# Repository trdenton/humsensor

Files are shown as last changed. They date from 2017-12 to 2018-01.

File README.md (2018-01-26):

# Humidity Sensor Solution

A basic wireless humidity sensor solution.  A work in progress.  Get your PCBs at https://www.pcbway.com/project/shareproject/W04152ASD12_humxmit_v2.html

Check out the writeup here:
https://skullspace.ca/2017/12/23/wireless-humidity-sensor-part-1-hardware-design/

## Hardware

Check out the KiCAD design files for the transmitter/sensor in 'tx\_pcb'

## Software

### Receiver

The receiver is based on an arduino mega (due to what I had laying around) and an nRF24L01+ module.  The sketch can be fond in 'hum\_sw/humrx'

### Transmitter

The transmitter is based on an attiny87, si7006, and nrf24L01+.  You can find it's source code in 'hum\_sw/humtx'.  It requires avrlibc and GNU make.  the 'prog' subdirectory contains a scrip that will flash the transmitter PCB via avrdude.  The included copy of avrdude is for my convenience, it is compiled for linux amd64

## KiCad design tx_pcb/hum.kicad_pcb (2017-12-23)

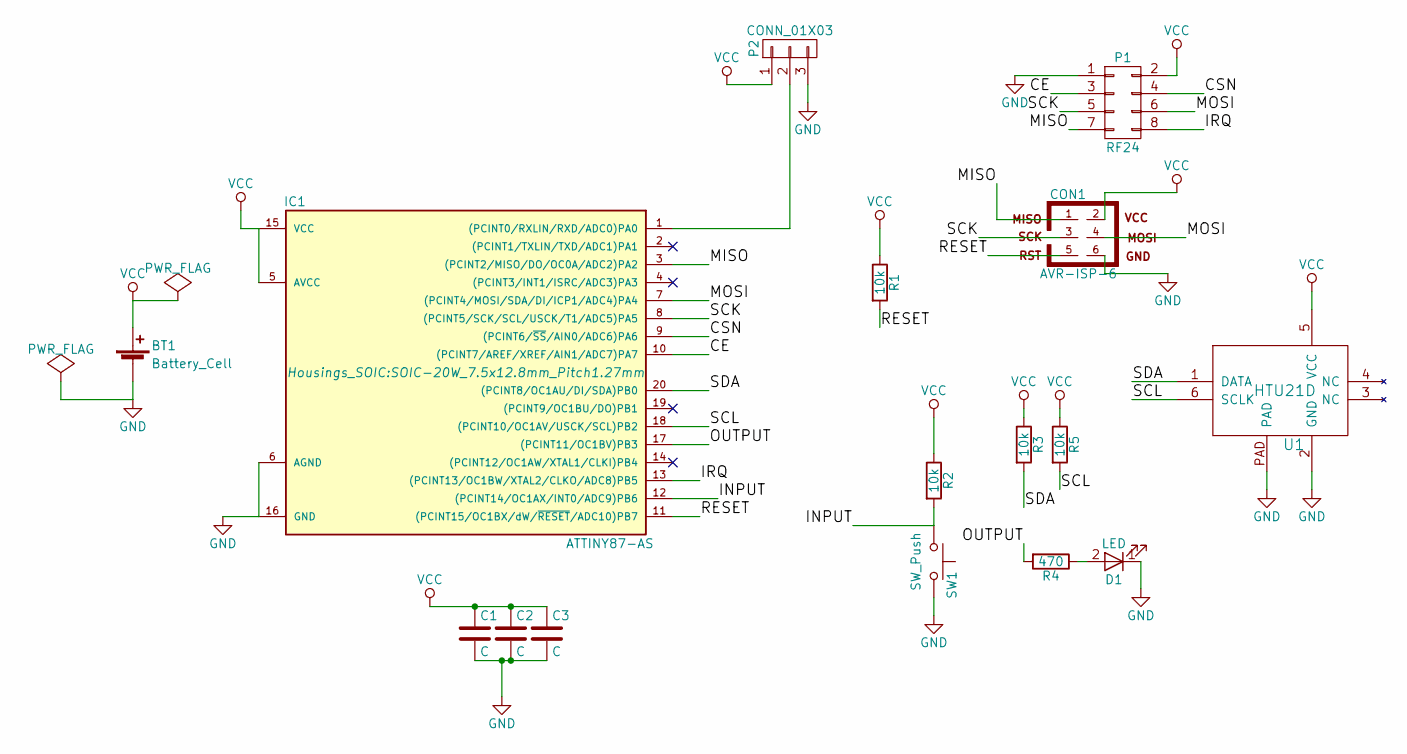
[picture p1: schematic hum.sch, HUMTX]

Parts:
BT1: Battery_Cell; battery
C1, C2, C3: C; C_0402
CON1: AVR-ISP-6; Pin_Header_Straight_2x03
D1: LED; LED_1206
IC1: ATTINY87-AS; SOIC-20W_7.5x12.8mm_Pitch1.27mm
P1: RF24; Socket_Strip_Straight_2x04
P2: CONN_01X03; Socket_Strip_Straight_1x03
R1, R2, R3, R5: 10k; R_0402
R4: 470; R_0402
SW1: SW_Push; switch
U1: HTU21D

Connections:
/CE: IC1.10 ((PCINT7/AREF/XREF/AIN1/ADC7)PA7), P1.3
/CSN: IC1.9 ((PCINT6/~SS~/AIN0/ADC6)PA6), P1.4
/INPUT: IC1.12 ((PCINT14/OC1AX/INT0/ADC9)PB6), R2.2, SW1.1
/IRQ: IC1.13 ((PCINT13/OC1BW/XTAL2/CLKO/ADC8)PB5), P1.8
/MISO: CON1.1, IC1.3 ((PCINT2/MISO/DO/OC0A/ADC2)PA2), P1.7
/MOSI: CON1.4, IC1.7 ((PCINT4/MOSI/SDA/DI/ICP1/ADC4)PA4), P1.6
/OUTPUT: IC1.17 ((PCINT11/OC1BV)PB3), R4.2
/RESET: CON1.5, IC1.11 ((PCINT15/OC1BX/dW/~RESET~/ADC10)PB7), R1.2
/SCK: CON1.3, IC1.8 ((PCINT5/SCK/SCL/USCK/T1/ADC5)PA5), P1.5
/SCL: IC1.18 ((PCINT10/OC1AV/USCK/SCL)PB2), R5.2, U1.6 (SCLK)
/SDA: IC1.20 ((PCINT8/OC1AU/DI/SDA)PB0), R3.2, U1.1 (DATA)
GND: BT1.2 (-), C1.2, C2.2, C3.2, CON1.6, D1.1 (K), IC1.6 (AGND), IC1.16 (GND), P1.1, P2.3, SW1.2, U1.2 (GND), U1.PAD
unnamed: D1.2 (A), R4.1
unnamed: IC1.1 ((PCINT0/RXLIN/RXD/ADC0)PA0), P2.2
VCC: BT1.1 (+), C1.1, C2.1, C3.1, CON1.2, IC1.5 (AVCC), IC1.15 (VCC), P1.2, P2.1, R1.1, R2.1, R3.1, R5.1, U1.5 (VCC)

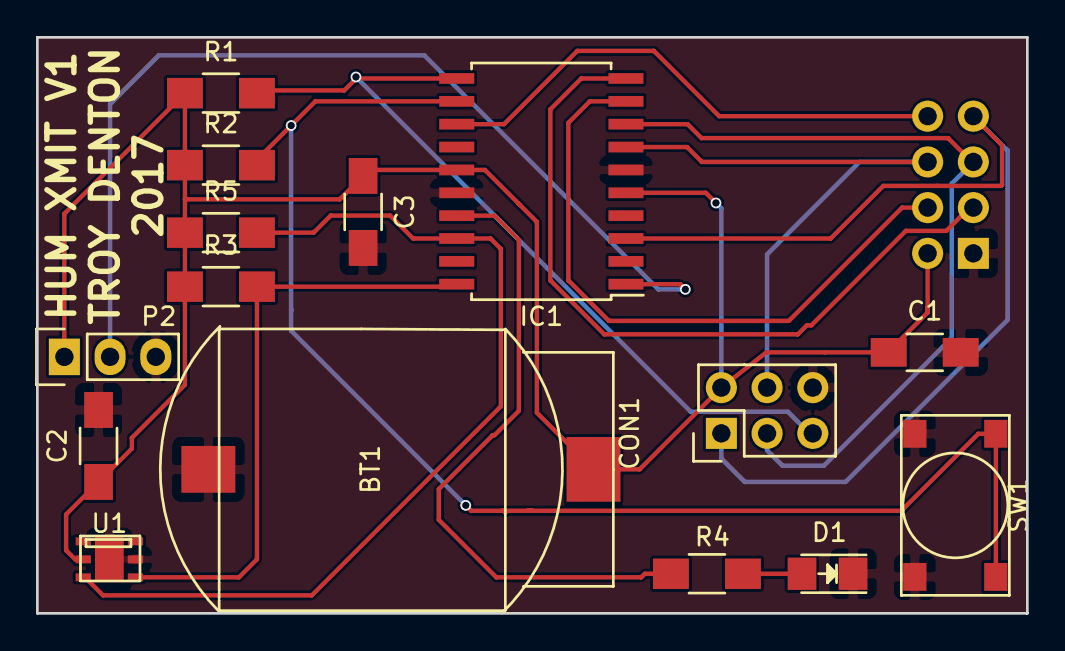
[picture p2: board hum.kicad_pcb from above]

Board: 2 copper layers, 55.0 x 32.0 mm, 16 parts (1 on the bottom side), 15 nets.

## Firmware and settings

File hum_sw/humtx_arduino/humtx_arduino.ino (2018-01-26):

#include <Si7006.h>

#include <RF24_config.h>
#include <printf.h>
#include <nRF24L01.h>
#include <RF24.h>

RF24 radio(7,6);
Si7006 hum;
const int led_pin=11;
byte address[] = "abcde";

void setup() {
  // put your setup code here, to run once:
  pinMode(led_pin,OUTPUT);

  blink(1);
  radio.begin();
  radio.setPALevel(RF24_PA_LOW);
  radio.setAutoAck(false);
  radio.setChannel(2);
  radio.setCRCLength(RF24_CRC_8);
  radio.setPayloadSize(sizeof(float));
  radio.setDataRate(RF24_250KBPS);
  radio.openWritingPipe(address);
  radio.stopListening();
  blink(1);
  if(!hum.begin())
  {
    while(1);
  }
}

void blink(int n)
{
  while(n)
  {
    digitalWrite(led_pin,HIGH);
    delay(100);
    digitalWrite(led_pin,LOW);
    delay(100);
    n--;
  }
}


void loop() {
  float humidity;
  boolean mode=false;
  // put your main code here, to run repeatedly:
  blink(1);
  
  delay(500);
  hum.getTemperature(humidity,mode);
  radio.write((void*)&humidity,sizeof(float));
}

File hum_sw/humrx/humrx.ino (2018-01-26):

/*
* Getting Started example sketch for nRF24L01+ radios
* This is a very basic example of how to send data from one node to another
* Updated: Dec 2014 by TMRh20
*/

#include <SPI.h>
#include "RF24.h"

/****************** User Config ***************************/
/***      Set this radio as radio number 0 or 1         ***/

/* Hardware configuration: Set up nRF24L01 radio on SPI bus plus pins 7 & 8 */
RF24 radio(7,8);
/**********************************************************/

byte address[] = "abcde";
byte address2[] = "fucky";

// Used to control whether this node is sending or receiving

void setup() {
  Serial.begin(115200);
  Serial.println(F("Starting..."));
  
  radio.begin();

  // Set the PA Level low to prevent power supply related issues since this is a
 // getting_started sketch, and the likelihood of close proximity of the devices. RF24_PA_MAX is default.
  radio.setPALevel(RF24_PA_LOW);


  radio.setAutoAck(false);
  radio.setChannel(2);
  radio.setCRCLength(RF24_CRC_8);
  radio.setPayloadSize(sizeof(float));
  radio.setDataRate(RF24_250KBPS);
  radio.openReadingPipe(0,address);
  radio.openReadingPipe(1,address2);
  radio.printDetails();
  // Start the radio listening for data
  Serial.println("Start listening...");
  radio.startListening();
}

void loop() {

    float dat;
    
    if( radio.available()){
      Serial.println("Read a thing!");                                                              // Variable for the received timestamp
      while (radio.available()) {                                   // While there is data ready
        radio.read( (void*)&dat,sizeof(float) );             // Get the payload
        Serial.println(dat);
      }
        
    }

} // Loop

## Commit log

2017-12-23 added all projects into one repo
    [hum-B.Cu.gbr, hum-B.Mask.gbr, hum-B.SilkS.gbr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]
2017-12-23 add link to PCBs
